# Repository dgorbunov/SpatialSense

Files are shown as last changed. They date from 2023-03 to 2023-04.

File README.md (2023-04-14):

## SpatialSense
SpatialSense is a wireless haptic feedback system for the visually impaired. It was created for ETH Zurich's 2023 Cybathlon Vision Assistance Race in the Dynamic and Autonomous Robotic System (DARoS) Lab at UMass Amherst.

Front
Back
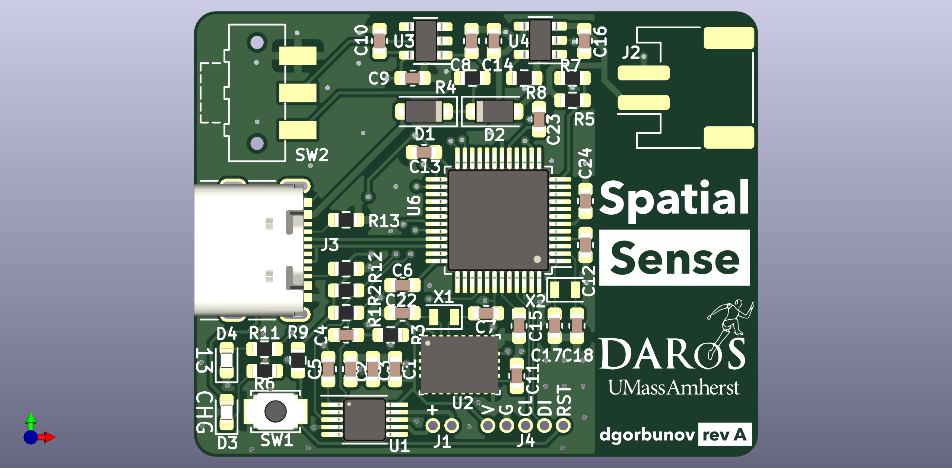
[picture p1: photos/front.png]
Front


More information about SpatialSense is available in [this presentation](https://github.com/dgorbunov/SpatialSense/blob/main/SpatialSense.pdf).

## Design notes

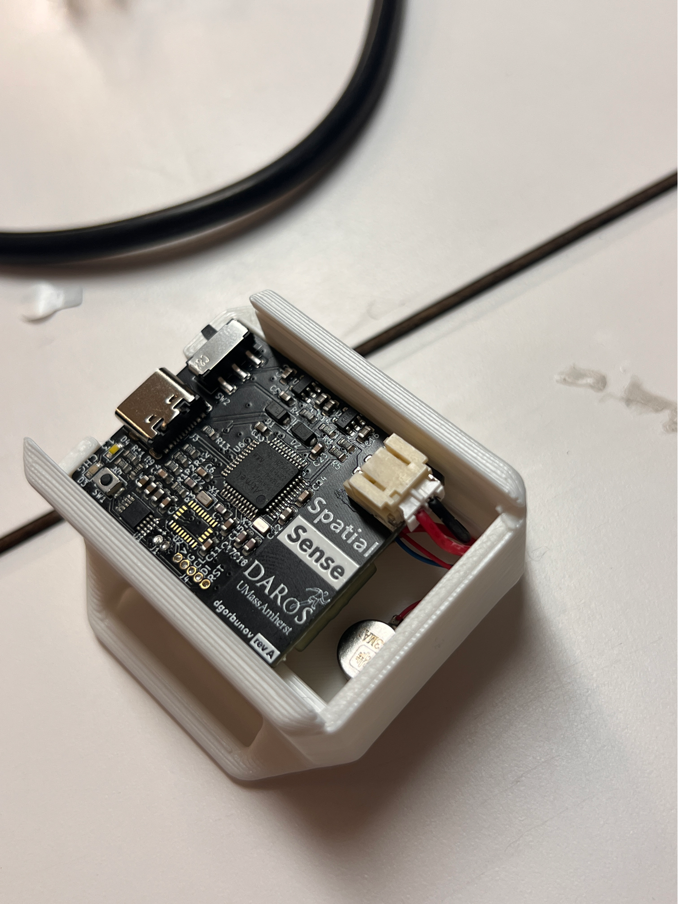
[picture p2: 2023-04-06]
photos/case2.png

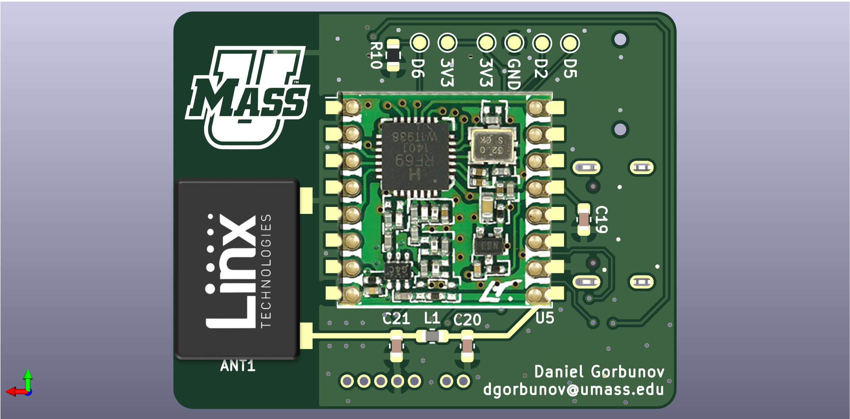
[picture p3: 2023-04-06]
photos/back.png

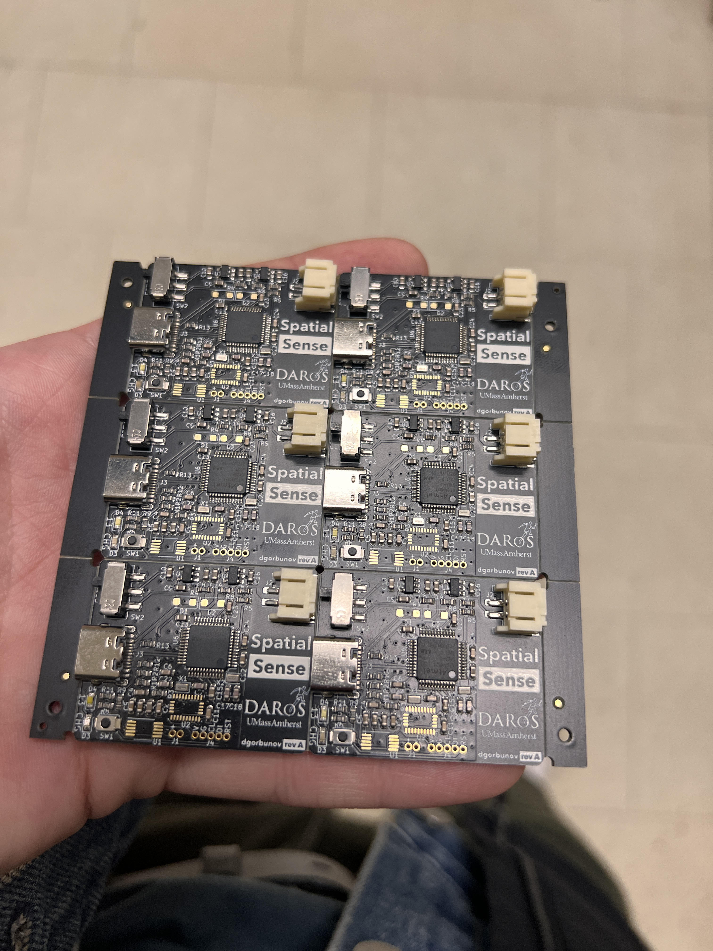
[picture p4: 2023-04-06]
photos/panelized.png

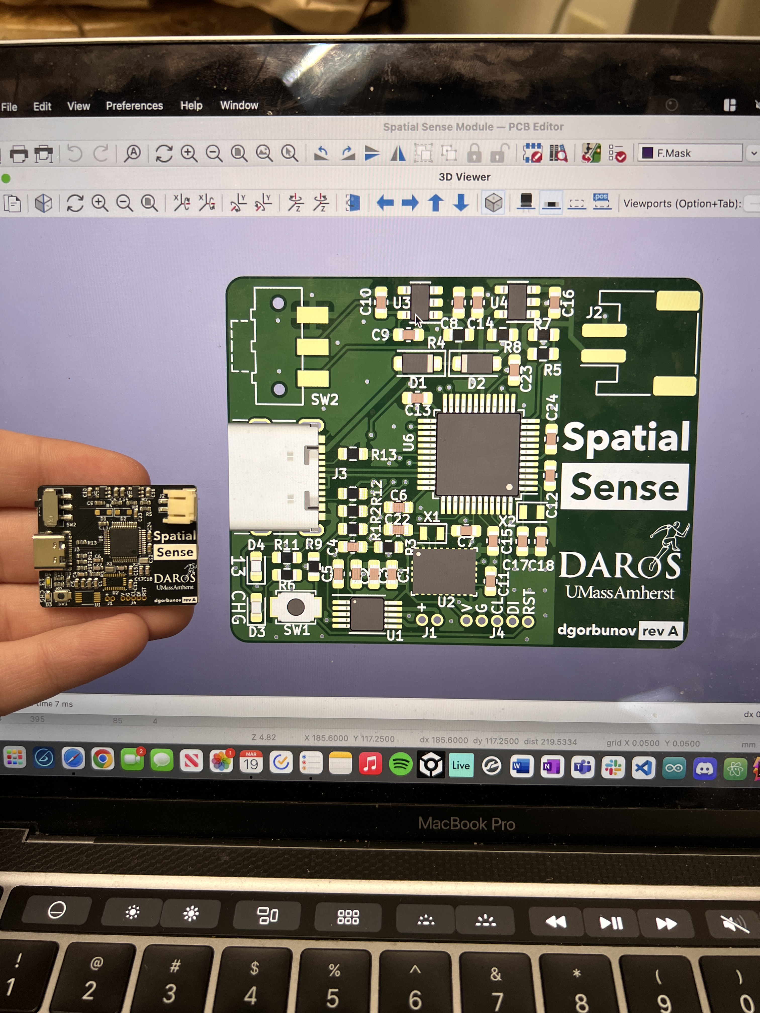
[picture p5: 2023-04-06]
photos/comparison.png

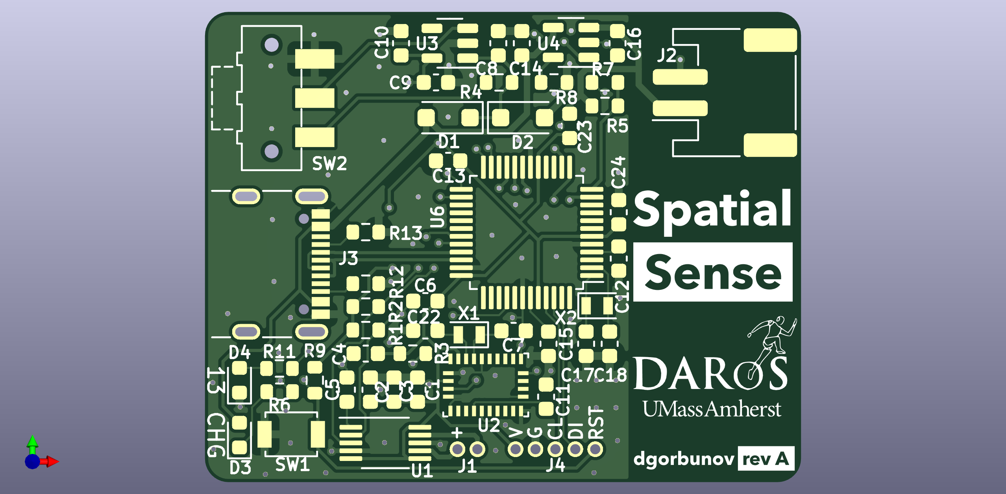
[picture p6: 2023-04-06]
photos/front_unpopulated.png

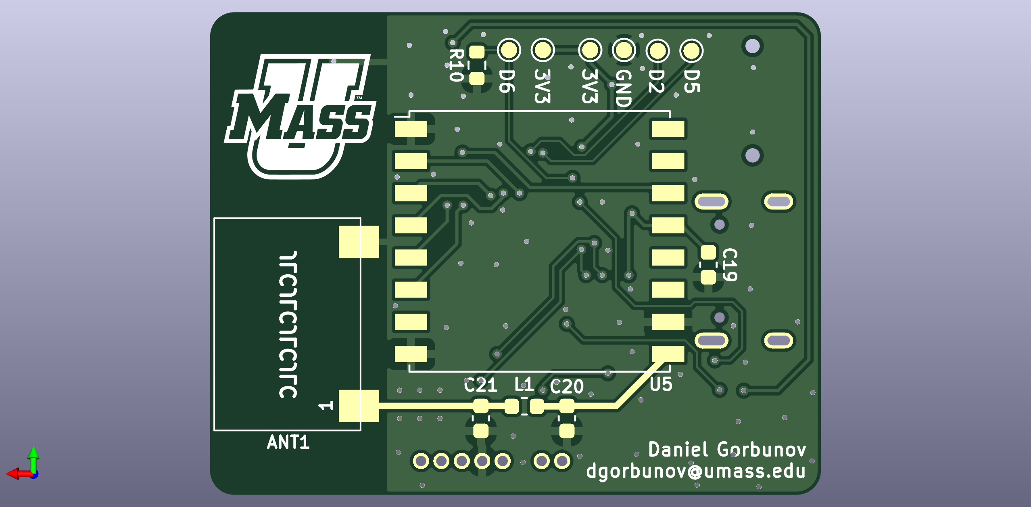
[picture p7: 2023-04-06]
photos/back_unpopulated.png

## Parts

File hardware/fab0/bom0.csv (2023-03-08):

Comment | Designator | Footprint | LCSC
TestPoint | GND_B1,GND_LC1,D5_LC1,D6_LC1,3V3_B1,3V3_LC1 | TestPoint:TestPoint_Pad_D1.0mm
Antenna_Shield | ANT1 | RF_Antenna:ANT-915-uSP410
0.1uF | C1,C4,C11,C22,C23,C24 | Capacitor_SMD:C_0603_1608Metric
1uF | C2,C5,C10,C12,C15 | Capacitor_SMD:C_0603_1608Metric
NP | C20,C21 | Capacitor_SMD:C_0603_1608Metric
10uF | C3,C8,C9,C13,C14,C16,C19 | Capacitor_SMD:C_0603_1608Metric
22pF | C6,C7,C17,C18 | Capacitor_SMD:C_0603_1608Metric
MBR1020VL | D1,D2 | Diode_SMD:D_SOD-123F
CHG | D3 | LED_SMD:LED_0603_1608Metric
13 | D4 | LED_SMD:LED_0603_1608Metric
Conn_01x02 | J1 | Connector_PinHeader_1.27mm:PinHeader_1x02_P1.27mm_Vertical
Conn_01x04 | J2 | Connector_JST:JST_PH_S2B-PH-SM4-TB_1x02-1MP_P2.00mm_Horizontal
USB_C_Receptacle_USB2.0 | J3 | Connector_USB:USB_C_Receptacle_GCT_USB4105-xx-A_16P_TopMnt_Horizontal
Conn_01x05 | J4 | Connector_PinHeader_1.27mm:PinHeader_1x05_P1.27mm_Vertical
0H | L1 | Inductor_SMD:L_0603_1608Metric
10k | R1,R2,R3,R8,R9,R10 | Resistor_SMD:R_0603_1608Metric
100 | R11 | Resistor_SMD:R_0603_1608Metric
5.1k | R12,R13 | Resistor_SMD:R_0603_1608Metric
100k | R4,R5,R7 | Resistor_SMD:R_0603_1608Metric
150 | R6 | Resistor_SMD:R_0603_1608Metric
RESET | SW1 | Button_Switch_SMD:SW_SPST_B3U-1000P
REG_EN | SW2 | Button_Switch_SMD:SW_SPDT_CK-JS102011SAQN
DRV2605LDGS | U1 | Package_SO:VSSOP-10_3x3mm_P0.5mm
BNO085 | U2 | Package_LGA:LGA-28_5.2x3.8mm_P0.5mm
AP2112K-3.3 | U3 | Package_TO_SOT_SMD:SOT-23-5
MCP73831-2-OT | U4 | Package_TO_SOT_SMD:SOT-23-5
RFM69HCW | U5 | RF_Module:HOPERF_RFM9XW_SMD
ATSAMD21G18A-A | U6 | Package_QFP:TQFP-48_7x7mm_P0.5mm
32.768kHz | X1,X2 | Crystal:Crystal_SMD_2012-2Pin_2.0x1.2mm

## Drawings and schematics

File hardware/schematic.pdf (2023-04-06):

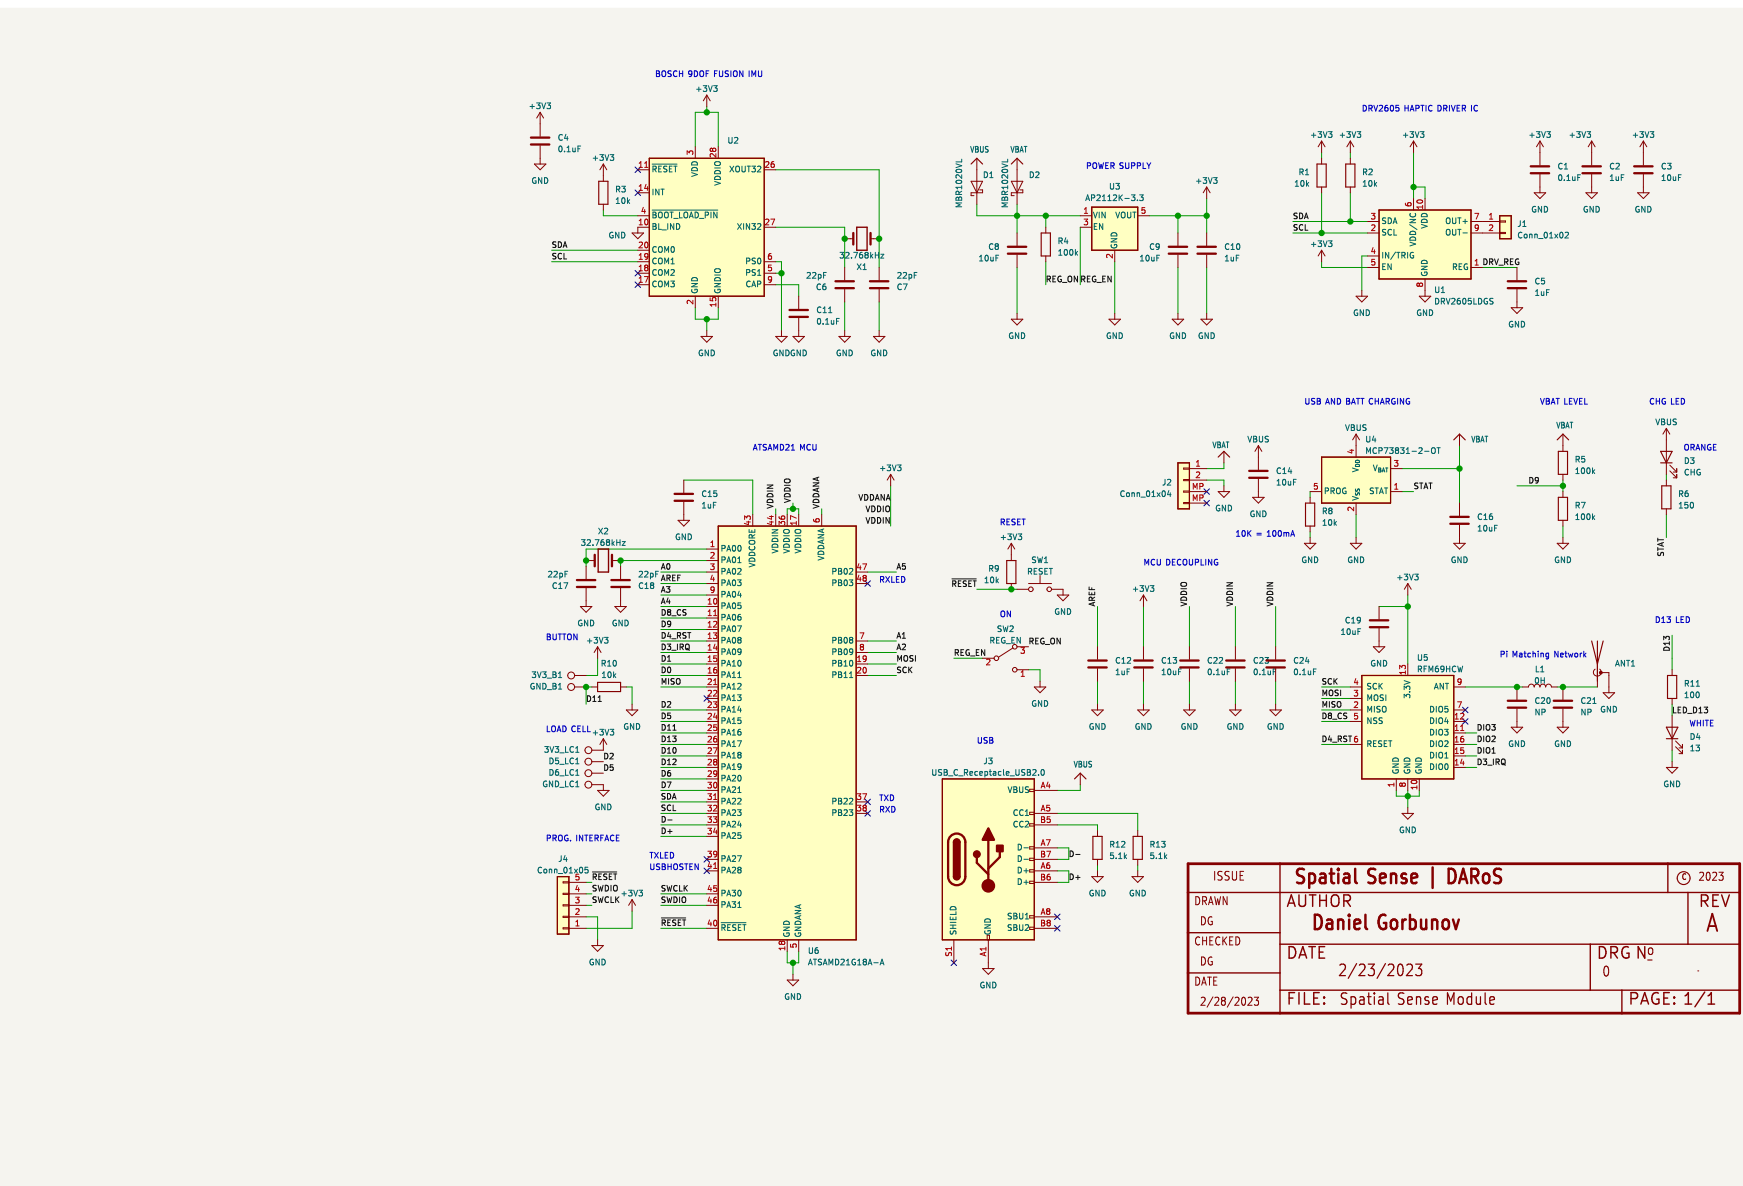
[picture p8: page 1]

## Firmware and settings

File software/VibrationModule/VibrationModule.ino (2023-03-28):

#include <SPI.h>
#include <RH_RF69.h>
#include <RHReliableDatagram.h>
#include <Wire.h>
#include "Adafruit_DRV2605.h"

#define HOST_ADDRESS 3

#define RF69_FREQ 915.0
#define RFM69_CS 8
#define RFM69_INT 3
#define RFM69_RST 4

#define VIBRATION_TIMEOUT 25 // ms with no effect signal to turn off

RH_RF69 rf69(RFM69_CS, RFM69_INT);
RHReliableDatagram RF69Manager(rf69, HOST_ADDRESS);

Adafruit_DRV2605 drv;

uint8_t buf[RH_RF69_MAX_MESSAGE_LEN];
uint8_t currentEffect = 0;
unsigned long timer = 0;

void setup() {
  Serial.begin(115200);
  delay(3000);

  pinMode(LED_BUILTIN, OUTPUT);     
  pinMode(RFM69_RST, OUTPUT);
  digitalWrite(RFM69_RST, LOW);

  // Manual reset.
  digitalWrite(RFM69_RST, HIGH);
  delay(10);
  digitalWrite(RFM69_RST, LOW);
  delay(10);
  
  while (!RF69Manager.init()) {
    Serial.println("RFM69 radio init failed. Trying again....");
    delay(250);
  }

  Serial.println("RFM69 radio init OK!");
  if (!rf69.setFrequency(RF69_FREQ)) {
    Serial.println("setFrequency failed");
  }

  rf69.setTxPower(20, true);  // range from 14-20 for power, 2nd arg must be true for 69HCW

  // The encryption key has to be the same as the one in the server
  // uint8_t key[] = { 0x01, 0x02, 0x03, 0x04, 0x05, 0x06, 0x07, 0x08,
  //                   0x01, 0x02, 0x03, 0x04, 0x05, 0x06, 0x07, 0x08};
  // rf69.setEncryptionKey(key);

  Serial.print("RFM69 radio @");
  Serial.print((int)RF69_FREQ);
  Serial.println(" MHz");

  if (! drv.begin()) {
    Serial.println("Could not find DRV2605");
    while (1) delay(10);
  }

  autocal();
  // nocal();
  
  drv.selectLibrary(1);
  drv.setMode(DRV2605_MODE_INTTRIG);
  currentEffect = 0;
  drv.setWaveform(0, currentEffect);
  drv.go();
}

void autocal() {
    /**
    a. ERM_LRA—selectionwilldependondesiredactuator.
    b. FB_BRAKE_FACTOR[2:0] — A value of 2 is valid for most actuators.
    c. LOOP_GAIN[1:0] — A value of 2 is valid for most actuators.
    d. RATED_VOLTAGE[7:0] — See the Rated Voltage Programming section for calculating the correct register value.
    e. OD_CLAMP[7:0] — See the Overdrive Voltage-Clamp Programming section for calculating the correct register value.
    f. AUTO_CAL_TIME[1:0] — A value of 3 is valid for most actuators.
    g. DRIVE_TIME[3:0]—SeetheDrive-TimeProgrammingforcalculatingthecorrectregistervalue.
    h. SAMPLE_TIME[1:0] — A value of 3 is valid for most actuators.
    i. BLANKING_TIME[1:0] — A value of 1 is valid for most actuators.
    j. IDISS_TIME[1:0] — A value of 1 is valid for most actuators

    Online values:
    uiBrakeFactor = 2 
    uiLoopGain = 2 
    uiBEMFGain = 3 
    uiRatedVoltage = 61 
    uiClampVoltage = 117 
    uiAutocalTime = 2 
    uiDriveTime = 13 
    uiSampleTime = 1 
    uiBlankingTime = 2 
    uiIDissTime = 3 
    uiZCDetTime = 0    
  **/

  // Set auto-calibration mode
  drv.setMode(DRV2605_MODE_AUTOCAL);

  // Set LRA, FB_BRAKE_FACTOR, LOOP_GAIN
  uint8_t feedback_val = 0;
  const uint8_t FB_BRAKE_FACTOR = 4;
  const uint8_t LOOP_GAIN = 3;
  feedback_val |= (1 << 7);  // Set LRA mode
  feedback_val |= (FB_BRAKE_FACTOR << 4);  // Set Brake Factor to 2
  feedback_val |= (LOOP_GAIN << 2);  // Set Loop Gain to 2
  drv.writeRegister8(0x1A, feedback_val);

  // Set RATED_VOLTAGE
  // Equation: (1.85*sqrt(1-(4*300*10^-6+ 300 * 10^-6)*235))/(20.58*10^-3) = 72
  const uint8_t RATED_VOLTAGE = 78;
  drv.writeRegister8(0x16, RATED_VOLTAGE);

  // Set OD_CLAMP
  // Equation: 1.85/(21.22*10^-3) = 87
  const uint8_t OD_CLAMP = 90;
  drv.writeRegister8(0x17, OD_CLAMP);

  // Set AUTO_CAL_TIME, ZC_DET_TIME (DEFAULTS)
  uint8_t ctrl4_val = 0;
  const uint8_t ZC_DET_TIME = 0;
  const uint8_t AUTO_CAL_TIME = 3;
  ctrl4_val |= (ZC_DET_TIME << 6); // ZC_DET_TIME (do we need this?)
  ctrl4_val |= (AUTO_CAL_TIME << 4);  // Set auto cal time to 1000ms (min) to 1200ms (max)
  drv.writeRegister8(0x1E, ctrl4_val);

  // Set DRIVE_TIME
  // (((1/235)*0.5*1000)-0.5)/0.1
  const uint8_t DRIVE_TIME = 16; 
  uint8_t ctrl1_val = 0;
  ctrl1_val |= (DRIVE_TIME & 0x1f);
  drv.writeRegister8(0x1B, ctrl1_val);

  // Set SAMPLE_TIME, BLANKING_TIME, IDISS_TIME (DEFAULTS)
  uint8_t ctrl2_val = 0;
  const uint8_t SAMPLE_TIME = 3;
  const uint8_t BLANKING_TIME = 1;
  const uint8_t IDISS_TIME = 1;
  ctrl2_val |= (SAMPLE_TIME << 4);  // Set sample to 300 us
  ctrl2_val |= (BLANKING_TIME << 2);  // Set blanking time to 25 us
  ctrl2_val |= (IDISS_TIME << 0);  // Set idiss time to 25 us
  drv.writeRegister8(0x1C, ctrl2_val);

  // Start auto-calibration
  drv.go();

  uint8_t go = 1;
  uint8_t i = 0;
  const uint8_t loop_delay = 100;
  const uint8_t timeout = 4000;

  // Wait for autocalibration to finish
  do {
    go = drv.readRegister8(DRV2605_REG_GO);
    delay(loop_delay);
    ++i;
  } while (go == 1 && i < timeout / loop_delay);

  Serial.print("Autocal Result: ");
  uint8_t DIAG_RESULT = (drv.readRegister8(0x00) & ( 1 << 3 )) >> 3;
  if (!DIAG_RESULT) Serial.println("SUCCESS");
  else Serial.println("FAILED");
}

void nocal() {
  drv.useLRA();
}

void loop() {
  // Wait for a message addressed to us from the client
  uint8_t len = sizeof(buf);
  uint8_t from;
  if (RF69Manager.recvfrom(buf, &len, &from)) {
    buf[len] = 0; // zero out remaining string
    
    // Serial.print("Got packet from #"); Serial.print(from);
    // Serial.print(" [RSSI :");
    // Serial.print(rf69.lastRssi());
    // Serial.print("] : ");
    // Serial.print((char*)buf);
    // Serial.print(" ");
    // Serial.println((int)buf[0]);

    if (currentEffect != (int)buf[0]) {
      currentEffect = (int)buf[0];
      drv.setWaveform(0, currentEffect);
      Serial.println("Set Waveform to " + (String)currentEffect);      
    }

    timer = millis();
  }

  // Serial.println(currentEffect);

  if (currentEffect != 0 && millis() - timer >= VIBRATION_TIMEOUT) {
    currentEffect = 0;
    drv.setWaveform(0, 0);
    Serial.println("Zero Waveform");
  }

  float bat_voltage = (analogRead(9) / 1023.0) * 6.6;
  if (bat_voltage < 3.5) blinkAsync(300);

  drv.go();
}

unsigned long ledTimer = 0;

void blinkAsync(int delay) {
  if (millis() - ledTimer > delay) {
    digitalWrite(LED_BUILTIN, !digitalRead(LED_BUILTIN));
    Serial.println("Batt low!");
    ledTimer = millis();
  }  
}

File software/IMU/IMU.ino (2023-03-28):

#include <Wire.h>
#include <Adafruit_Sensor.h>
#include <Adafruit_BNO055.h>
#include <utility/imumaths.h>

#include <SPI.h>
#include <RH_RF69.h>
#include <RHReliableDatagram.h>

#define HOST_ADDRESS 4

#define RF69_FREQ 915.0
#define RFM69_CS 8
#define RFM69_INT 3
#define RFM69_RST 4

// TO BE ADJUSTED
#define ANGLE_DEADZONE 3.50
#define ANGLE_CORRECTION_ROLL 0.88
#define ANGLE_CORRECTION_PITCH -0.81
#define SAMPLERATE_DELAY_MS 5

RH_RF69 RF69(RFM69_CS, RFM69_INT);
RHReliableDatagram RF69Mgr(RF69, HOST_ADDRESS);
uint8_t destAddr[4] = {
  0, // FL
  1, // BL
  2, // FR
  3  //BR
};

uint8_t effects[1] = {
  10 // 12 is higher frequency
};

Adafruit_BNO055 bno = Adafruit_BNO055(55, 0x28);
bool imuIdle = false;

void setup() {
  Serial.begin(115200);

  pinMode(RFM69_RST, OUTPUT);
  digitalWrite(RFM69_RST, LOW);

  // Manual reset.
  digitalWrite(RFM69_RST, HIGH);
  delay(10);
  digitalWrite(RFM69_RST, LOW);
  delay(10);

  while (!RF69Mgr.init()) {
    Serial.println("RFM69 radio init failed. Trying again....");
    delay(250);
  }

  Serial.println("RFM69 radio init OK!");
  if (!RF69.setFrequency(RF69_FREQ)) {
    Serial.println("setFrequency failed; using default");
  }

  RF69.setTxPower(20, true);  // range from 14-20 for power, 2nd arg must be true for 69HCW

  // The encryption key has to be the same as the one in the server
  // uint8_t key[] = { 0x01, 0x02, 0x03, 0x04, 0x05, 0x06, 0x07, 0x08,
  //                   0x01, 0x02, 0x03, 0x04, 0x05, 0x06, 0x07, 0x08 };

  // RF69.setEncryptionKey(key);

  Serial.print("RFM69 radio @");
  Serial.print((int)RF69_FREQ);
  Serial.println(" MHz");

  if(!bno.begin()) {
    Serial.print("No BNO055 detected ... Check your wiring or I2C ADDR!");
    while(1);
  }
  
  delay(1000);
  bno.setExtCrystalUse(true);
}

void loop() {
  sensors_event_t event;
  bno.getEvent(&event);

  float roll = (float) -1 * event.orientation.y + ANGLE_CORRECTION_ROLL;
  float pitch = wrapPitch((float) -1 * event.orientation.z) + ANGLE_CORRECTION_PITCH;

  Serial.print(F("Roll: "));
  Serial.print(roll);
  Serial.print(F(" Pitch :"));
  Serial.println(pitch);

  float bat_voltage = (analogRead(9) / 1023.0) * 6.6;
  if (bat_voltage < 3.5) blinkAsync(300);

  sendData(deadzone(roll), deadzone(pitch));
  delay(SAMPLERATE_DELAY_MS);
}

unsigned long ledTimer = 0;

void blinkAsync(int delay) {
  if (millis() - ledTimer > delay) {
    digitalWrite(LED_BUILTIN, !digitalRead(LED_BUILTIN));
    Serial.println("Batt low!");
    ledTimer = millis();
  }  
}

void sendData(float roll, float pitch) {
  // Serial.print(F("Roll: "));
  // Serial.print(roll);
  // Serial.print(F(" Pitch :"));
  // Serial.println(pitch);

  // Simplified X logic (FL: 0, BL: 1, FR: 2, BR: 3), 1 or 2 vibrations at a time
  if (roll != 0 && pitch != 0){
    uint8_t addr[1];
    if (roll > 0){
      if (pitch > 0){
        addr[0] = destAddr[1];
      } else {
        addr[0] = destAddr[0];
      }
    } else {
      if (pitch > 0){
        addr[0] = destAddr[3];
      } else {
        addr[0] = destAddr[2];
      }
    }

    writeMotors(addr, 1);

  } else if (roll != 0){
      uint8_t addr[2]={0, 0};
      if (roll > 0){
        addr[0] = destAddr[0], addr[1] = destAddr[1];
      } else {
        addr[0] = destAddr[2], addr[1] = destAddr[3];
      }

      writeMotors(addr, 2);

  } else if (pitch != 0) {
      uint8_t addr[2]={0, 0};

      if (pitch > 0){
        addr[0] = destAddr[1], addr[1] = destAddr[3];
      } else {
        addr[0] = destAddr[0], addr[1] = destAddr[2];      
      }

      writeMotors(addr, 2);

  } else if (!imuIdle) {
    imuIdle = true;
    // writeMotors(destAddr, 4);
  }
}

void writeMotors(uint8_t activeMotors[], int num) {
  imuIdle = false;
  byte buff[1] = {effects[0]};

  for (int i = 0; i < num; i++) {
    RF69Mgr.sendto(buff, 1, activeMotors[i]);
    // Serial.println("Writing to " + (String)activeMotors[i]);
  }
}

float deadzone(float input) {
  return abs(input) <= ANGLE_DEADZONE ? 0 : input;
}

float wrapPitch(float pitch) {
  if (pitch > 0) {
    return mapFloat(pitch, 180, 0, 0, 180);
  } else return mapFloat(pitch, -180, 0, 0, -180);
}

float mapFloat(float x, float in_min, float in_max, float out_min, float out_max) {
  return (x - in_min) * (out_max - out_min) / (in_max - in_min) + out_min;
}

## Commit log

2023-03-08 Initial commit, revA hw
    [Spatial Sense Module-B_Mask.gbs, Spatial Sense Module-B_Paste.gbp, Spatial Sense Module-B_Silkscreen.gbo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]
2023-04-06 Add schematic
